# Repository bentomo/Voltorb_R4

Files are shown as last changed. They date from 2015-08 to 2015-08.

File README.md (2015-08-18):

This is a custom Lithium Ion Charger and Power board for a Nintendo Gamecube Portable. The board design was made in KiCad and can be downloaded and edited with the open source KiCad software.

This may or may not be the final version of the board, it's struggling with heat issues right now and while it works with a heatsink it can push up to 100 degrees celcius without it. The operating temperature is 85 degrees celcius max so this is not the desired operating temperature. (Who would want to deal with it being that hot anyway!)

The charger IC is a Linear Technologies LTC4006-6 which charges a 7.4v Li-ION pack at 3 amperes. The charger also has smart load switching to power a load while chargin the batteries by limiting the charge current and prioritizing the load.

The board has an adjustable low battery LED on the back that can turn on when a battery voltage is reached, this is not accurate but it is simple for an important feature.

There are 2 switching regulators on the PCB. There is a RichTek RT7258 and a Texas Instruments TPS542951 on the board. The Richtek regulator is suppying the 1.9v line to power a gamecube and can source up to 10 amperes. The TI regulator is a dual output regulator for the 3.3v logic line and a 5v line that can each source 2 amperes for miscellaneous components such as fans, rumble motors, screens etc. 

As I said before this project is a work in progress and still has heat issues. It will charge a battery and power a gamecube as long as you are heatsinking the inductors.

I am not responsible for any damages to yourself or your properties. Batteries are nothing to fool with and if you're not careful and don't respect them then you do not deserve to work with this project.

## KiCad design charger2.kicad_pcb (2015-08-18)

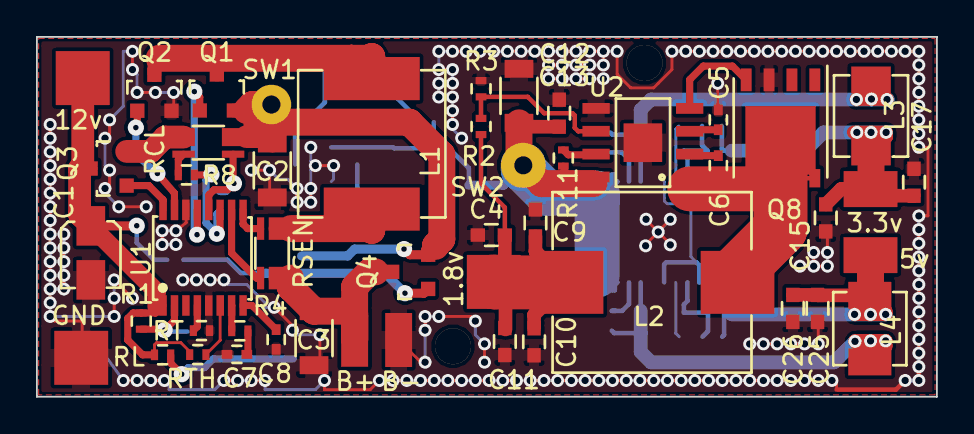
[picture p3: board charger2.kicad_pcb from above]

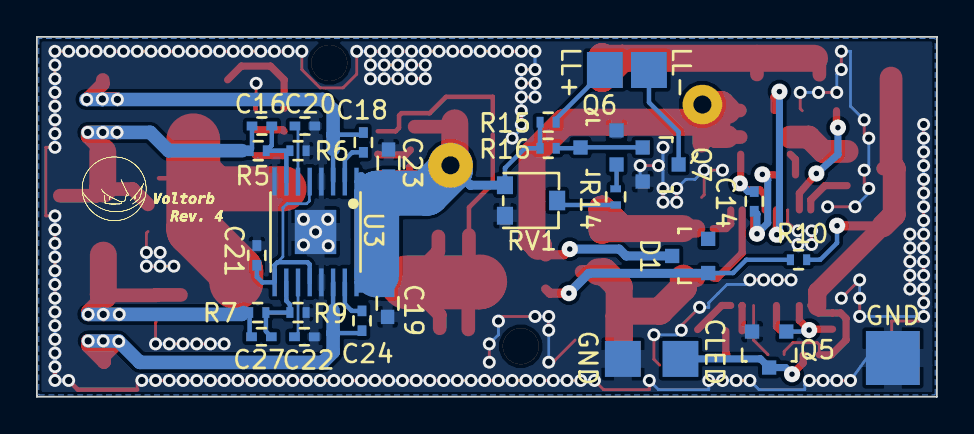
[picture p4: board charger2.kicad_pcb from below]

Board: 2 copper layers, 50.0 x 20.0 mm, 77 parts (29 on the bottom side), 43 nets.

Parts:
1.8v, 3.3v, 5v, 12v: SolderWirePad_single_2mmDrill
B+: SolderWirePad_single_2mmDrill
B-: SolderWirePad_single_2mmDrill
C1: .1u; nichicon_electrolytic
C2: 150u; C_1206
C3: 22u; C_1206
C4, C9, C10, C11, C15, C17, C25, C26: 22u; C_0603
C5, C6, C21: 1u; C_0402
C7: .12u; C_0402
C8, C20, C22: 4.7n; C_0402
C12: 10u; C_1206
C13, C19, C23: 10u; C_0603
C14: 15n; C_0402
C16, C27: 15p; C_0402
C18, C24: .1u; C_0402
CLED: SolderWirePad_single_2mmDrill
D1: 10v; SOT-23
GND: SolderWirePad_single_2mmDrill
GND#2, GND#3: SolderWirePad_single_2mmDrill
L1: 15u; Vishay_ER_inductor_15uH
L2: 1.5u; SRP1038A
L3: 2.2u; abracon-aspi-4020hi
L4: 3.3u; bourns-SRP4020TA
LL+: SolderWirePad_single_2mmDrill
LL-: SolderWirePad_single_2mmDrill
Q1, Q3, Q4: Q_PMOS; SOT-23
Q2: Q_NMOS; SOT-23
Q5, Q6, Q7: NPN; SOT-23
Q8: NMOS_vishay; SO-8_PowerPAK_Vishay_Single
R1, R10, R11, R14, R16: 100k; R_0402
R2: 28.7k; R_0402
R3, R6, R9: 22.1k; R_0402
R4: 6.04k; R_0402
R5: 73.2k; R_0402
R7: 124k; R_0402
R8: 5.1k; R_0402
R15: 1k; R_0402
RCL: .036; 1206_Kelvin
RL: 1k; R_0402
RSEN: .033; 1206_Kelvin
RT: 309k; R_0402
RTH: 309k; R_0402
RV1: POT; murata-pvz3a-pvz3g-pvz3h
SW1, SW2: SolderWirePad_single_2mmDrill
U1: LTC4006; SOP-16
U2: RT7258; 8-SOP+pad
U3: TPS54295PWPR; PDSO-16

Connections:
1.74v: 1.8v.1, C4.1, C9.1, C10.1, C11.1, L2.2, R2.1
3.3v: 3.3v.1, C15.2, C16.1, C17.2, L3.2, R5.1
5v: 5v.1, C25.2, C26.2, C27.1, L4.1, R7.1
12v: 12v.1, C1.1, Q3.1, R1.1, R10.1, RL.2, RTH.2, U1.1
CLED: CLED.1, Q5.1, RL.1
GND: B-.1, C1.2, C2.2, C3.2, C4.2, C5.2, C7.2, C8.2, C9.2, C10.2, C11.2, C12.2, C13.2, C15.1, C17.1, C19.1, C20.2, C21.2, C22.1, C23.1, C25.1, C26.1, GND.1, GND#2.1, GND#3.1, Q2.3, Q5.3, Q6.3, Q7.3, Q8.3, R3.1, R6.2, R9.2, RT.2, RV1.3, U1.5, U1.14, U2.5, U2.9, U3.4, U3.8, U3.13, U3.17
LLED+: LL+.1, R15.1
LLED-: LL-.1, Q7.1
unnamed: C5.1, U2.3
unnamed: C6.1, U2.2
unnamed: C6.2, L2.1, Q8.5, U2.1
unnamed: C7.1, R4.1
unnamed: C8.1, U1.8
unnamed: C14.2, R8.1, U1.11
unnamed: C16.2, R5.2, R6.1, U3.7
unnamed: C18.1, U3.2
unnamed: C18.2, L3.1, U3.3
unnamed: C20.1, U3.6
unnamed: C21.1, U3.5, U3.9, U3.12
unnamed: C22.2, U3.11
unnamed: C24.1, L4.2, U3.14
unnamed: C24.2, U3.15
unnamed: C27.2, R7.2, R9.1, U3.10
unnamed: D1.2, Q4.2, R10.2
unnamed: L1.1, RSEN.2, U1.9
unnamed: L1.2, Q1.1, Q2.1
unnamed: Q1.2, U1.13
unnamed: Q2.2, U1.15
unnamed: Q3.2, U1.16
unnamed: Q3.3, R8.2, RCL.2
unnamed: Q5.2, R1.2, U1.2
unnamed: Q6.1, Q7.2, R16.1
unnamed: Q6.2, R14.1
unnamed: Q8.4, U2.4
unnamed: R2.2, R3.2, U2.6
unnamed: R4.2, U1.7
unnamed: R11.1, U2.7
unnamed: R14.2, RV1.2
unnamed: RT.1, U1.4
unnamed: RTH.1, U1.6
SW1: C2.1, C14.1, D1.1, Q1.3, Q4.3, RCL.1, SW1.1, U1.12
SW2: C12.1, C13.1, C19.2, C23.2, R11.2, R15.2, R16.2, RV1.1, SW2.1, U2.8, U3.1, U3.16
batt: B+.1, C3.1, Q4.1, RSEN.1, U1.10

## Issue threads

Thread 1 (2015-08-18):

OverHeating

bentomo, 2015-08-18:
Charger Inductor overheats while pushing full charge and buck regulator inductors overheat and reach thermal limit after running a gamecube for about .5-1 hours.
